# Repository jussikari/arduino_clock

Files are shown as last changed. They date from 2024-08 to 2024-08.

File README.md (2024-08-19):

# Arduino wooden clock project

## General

This is a wooden clock project which is capable of beautifully showing time, date or alternating between both. It also has the capability of setting the time and showing a welcome message when turned on.

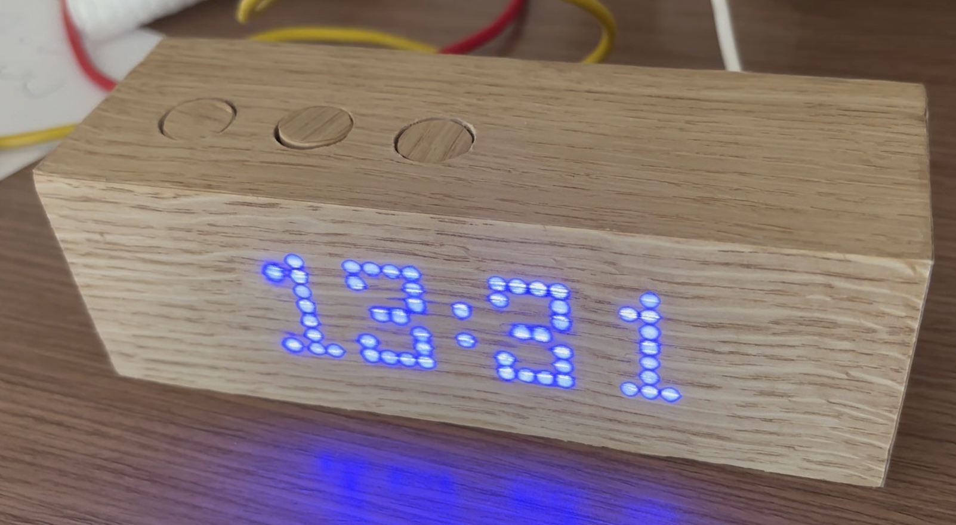
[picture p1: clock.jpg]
Clock


## Design

Construction and measurements are available in arduino_clock.scad. Open the file with OpenSCAD.

## Requirements:

- Arduino Nano (Arduino micro will also fit)
- Small perfboard for soldering
- MAX2719 4pcs 8x8 led display grids (I purchased 4 connected modules)
- RTC module (e.g. TinyRTC)
- 3pcs 10kOhm resistors
- 3pcs small push buttons
- Some wires

Also, for building the case I used 12mm veneer which I had lying around. SCAD file is for 12mm thickness. I decorated veneer with wooden film, specifically this.

https://www.aliexpress.com/item/1005005327698778.html?spm=a2g0o.order_list.order_list_main.20.3a6b1802T0AMOs

One could use something else. Or maybe spray paint the case - in which case one would need transparent film to be put on led surface for painting. Paint layer needs to be thin enough to pass through the light.

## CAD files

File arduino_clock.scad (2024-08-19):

VENEER_WIDTH = 12;
CONTAINER_HEIGHT = 32;
CONTAINER_WIDTH = 146;
BUTTON_R = 8;
BUTTON_X1 = VENEER_WIDTH + BUTTON_R + 0;
BUTTON_Y = VENEER_WIDTH + 0;
BUTTON_DIST = 20;
POWER_R = 5;
EPSILON = 0.01;

// bottom
cube([CONTAINER_WIDTH + 2 * VENEER_WIDTH, CONTAINER_HEIGHT + VENEER_WIDTH, VENEER_WIDTH]);
echo("Bottom/top: ", CONTAINER_WIDTH + 2 * VENEER_WIDTH, "x", CONTAINER_HEIGHT + VENEER_WIDTH);

// left
translate([0, 0, VENEER_WIDTH]) {
    cube([VENEER_WIDTH, CONTAINER_HEIGHT + VENEER_WIDTH, CONTAINER_HEIGHT]);
}
echo("Left/right: ", CONTAINER_HEIGHT + VENEER_WIDTH, "x", CONTAINER_HEIGHT);
    
// right    
translate([CONTAINER_WIDTH+VENEER_WIDTH, 0, VENEER_WIDTH]) {    
    cube([VENEER_WIDTH, CONTAINER_HEIGHT + VENEER_WIDTH, CONTAINER_HEIGHT]);
}

// top
translate([0, 0, CONTAINER_HEIGHT + VENEER_WIDTH]) {
    difference() {
        // top
        cube([CONTAINER_WIDTH + 2 * VENEER_WIDTH, CONTAINER_HEIGHT + VENEER_WIDTH, VENEER_WIDTH]);
        
        // button holes
        for (i = [0:2]) {
            translate([BUTTON_X1 + i * BUTTON_DIST, BUTTON_R + BUTTON_Y, -EPSILON]) {
                cylinder(h=VENEER_WIDTH + 2*EPSILON, r=BUTTON_R);
            }
        }
    }
    
    // buttons
    for (i = [0:2]) {
        translate([BUTTON_X1 + i * BUTTON_DIST, BUTTON_Y + BUTTON_R, 1]) {
            color("#ffff99") {
                cylinder(h=VENEER_WIDTH + 2*EPSILON, r=BUTTON_R - EPSILON);
            }
        }
    }
}

// backside
translate([0, CONTAINER_HEIGHT + VENEER_WIDTH, 0]) {
    difference() {
        cube([CONTAINER_WIDTH + 2 * VENEER_WIDTH, VENEER_WIDTH, CONTAINER_HEIGHT + 2 * VENEER_WIDTH]);
        translate([CONTAINER_WIDTH + VENEER_WIDTH - POWER_R, -EPSILON, VENEER_WIDTH + POWER_R]) {
            rotate([270, 0, 0]) {
                cylinder(h=VENEER_WIDTH + 2 * EPSILON, r=POWER_R);
            }
        }
        translate([VENEER_WIDTH/2, 0, VENEER_WIDTH/2]) {
            rotate([270, 0, 0]) {
                cylinder(h=VENEER_WIDTH + 2 * EPSILON, r=1);
            }
        }
        translate([CONTAINER_WIDTH+VENEER_WIDTH*1.5, 0, VENEER_WIDTH/2]) {
            rotate([270, 0, 0]) {
                cylinder(h=VENEER_WIDTH + 2 * EPSILON, r=1);
            }
        }
        translate([CONTAINER_WIDTH+VENEER_WIDTH*1.5, 0, CONTAINER_HEIGHT + VENEER_WIDTH * 1.5]) {
            rotate([270, 0, 0]) {
                cylinder(h=VENEER_WIDTH + 2 * EPSILON, r=1);
            }
        }
        translate([VENEER_WIDTH/2, 0, CONTAINER_HEIGHT + VENEER_WIDTH * 1.5]) {
            rotate([270, 0, 0]) {
                cylinder(h=VENEER_WIDTH + 2 * EPSILON, r=1);
            }
        }
    }
}
echo("Back: ", CONTAINER_WIDTH + 2 * VENEER_WIDTH, "x", CONTAINER_HEIGHT + 2 * VENEER_WIDTH);


// front film
translate([0, -EPSILON, 0]) {
    color("#000000", 0.4) {
        cube([CONTAINER_WIDTH + 2 * VENEER_WIDTH, EPSILON, CONTAINER_HEIGHT + 2 * VENEER_WIDTH]);
    }
}

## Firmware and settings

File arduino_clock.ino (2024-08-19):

#include <Arduino.h>

#include "MD_MAX72xx.h"
#include "MD_Parola.h"
#include "RTClib.h"
#include "SPI.h"

#include "font_data.h"
#include "button.h"
#include "debug.h"

// MAX7219 hardware type, size, and output pins:
#define HARDWARE_TYPE MD_MAX72XX::FC16_HW
#define MAX_DEVICES 4
#define CS_PIN 10
#define DATA_PIN 12
#define CLK_PIN 11

#define PIN_MODE 7
#define PIN_UP 6
#define PIN_DOWN 5

// Milliseconds between blinking digits in edit mode
#define BLINK_INTERVAL 200

// Milliseconds between changing time and date in alternate mode
#define ALTERNATE_INTERVAL 30000

enum State {
  STATE_INIT = 0,
  STATE_TIME = 1,
  STATE_DATE = 2,
  STATE_ALTERNATE = 3,
  STATE_EDIT
};
enum DisplayMode { TIME = 1, DATE = 2 };
enum EditMode { NONE = 0, MINUTE = 1, HOUR = 2, DAY = 3, MONTH = 4, YEAR = 5 };
struct NextView {
  bool isPending = true;
  textEffect_t effectIn = PA_SCROLL_DOWN;
  State state = STATE_TIME;
  DisplayMode displayMode = DisplayMode::TIME;
  bool showText = false;
} next;

LongPressButton modeButton(PIN_MODE);
RepeatButton upButton(PIN_UP);
RepeatButton downButton(PIN_DOWN);

int lastMinute = 0;
State state = State::STATE_INIT;
DisplayMode displayMode;

EditMode editMode = EditMode::NONE;
char displayString[10];
char hourString[3];
char minuteString[3];
char yearString[3];
char monthString[3];
char dayString[3];
unsigned long lastAlternateMillis = 0;

MD_Parola display = MD_Parola(HARDWARE_TYPE, CS_PIN, MAX_DEVICES);
RTC_DS1307 rtc;

void setString(char* str, EditMode modeMatch, int value) {
  int blink = (millis() / BLINK_INTERVAL) % 2;

  if (editMode != modeMatch || blink == 1) {
    sprintf(str, "%02d", value);
  } else {
    sprintf(str, "  ", value);
  }
}

void drawTime(textEffect_t in = PA_PRINT, textEffect_t out = PA_NO_EFFECT) {
  DateTime now = rtc.now();

  setString(hourString, EditMode::HOUR, now.hour());
  setString(minuteString, EditMode::MINUTE, now.minute());

  sprintf(displayString, "%s:%s", hourString, minuteString);
  display.setTextAlignment(PA_CENTER);
  display.setFont(0, largeDigitDont);
  display.displayText(displayString, display.getTextAlignment(),
                      display.getSpeed(), 0, in, out);
}

void drawDate(textEffect_t in = PA_PRINT, textEffect_t out = PA_NO_EFFECT) {
  DateTime now = rtc.now();

  setString(yearString, EditMode::YEAR, now.year() % 100);
  setString(monthString, EditMode::MONTH, now.month());
  setString(dayString, EditMode::DAY, now.day());

  sprintf(displayString, "%s.%s.-%s", dayString, monthString, yearString);
  display.setTextAlignment(PA_CENTER);
  display.setFont(0, smallDigitFont);
  display.displayText(displayString, display.getTextAlignment(),
                      display.getSpeed(), 0, in, out);
}

int numberOfDaysInMonth(int year, int month) {
  switch (month) {
    case 1:   // January
    case 3:   // March
    case 5:   // May
    case 7:   // July
    case 8:   // August
    case 10:  // October
    case 12:  // December
      return 31;
    case 4:   // April
    case 6:   // June
    case 9:   // September
    case 11:  // November
      return 30;
    case 2:  // February
      if ((year % 4 == 0 && year % 100 != 0) || year % 400 == 0) {
        return 29;
      } else {
        return 28;
      }
    default:
      return 0;
  }
}

void setup() {
  if (!rtc.begin()) {  // start the RTC module
    abort();
  }

  Debug::init();

  display.begin();
  display.setFont(0, nullptr);
  display.setIntensity(8); //0-15
  display.setPause(6);
  display.displayClear();

  display.displayText("Papan kello", PA_RIGHT, 130,
                      0, PA_SCROLL_LEFT, PA_SCROLL_LEFT);
}

void changeTime(int change) {
  DateTime now = rtc.now();

  if (editMode == EditMode::MINUTE) {
    rtc.adjust(DateTime(now.year(), now.month(), now.day(), now.hour(),
                        (now.minute() + change + 60) % 60, 0));

  } else if (editMode == EditMode::HOUR) {
    rtc.adjust(DateTime(now.year(), now.month(), now.day(),
                        (now.hour() + change + 24) % 24, now.minute(), 0));
  } else if (editMode == EditMode::DAY) {
    int daysInMonth = numberOfDaysInMonth(now.year(), now.month());
    rtc.adjust(
        DateTime(now.year(), now.month(),
                 (now.day() - 1 + change + daysInMonth) % daysInMonth + 1,
                 now.hour(), now.minute(), 0));
  } else if (editMode == EditMode::MONTH) {
    rtc.adjust(DateTime(now.year(), (now.month() - 1 + 12 + change) % 12 + 1,
                        now.day(), now.hour(), now.minute(), 0));
  } else if (editMode == EditMode::YEAR) {
    rtc.adjust(DateTime(2000 + (now.year() + change) % 100, now.month(),
                        now.day(), now.hour(), now.minute(), 0));
  }
}

void loop() {
  PressType modeButtonPress = modeButton.read();
  PressType upButtonPress = upButton.read();
  PressType downButtonPress = downButton.read();

  if (!next.isPending) {
    if (modeButtonPress == PRESS_TYPE_PRIMARY) {
      if (editMode == EditMode::NONE) {
        changeMode();
      } else {
        editMode = (EditMode)((editMode + 1) % 6);

        // Force redraw of current mode when exit editing
        if (editMode == EditMode::NONE) {
          lastMinute = -1;
        }
      }
    } else if (modeButtonPress == PRESS_TYPE_SECONDARY) {
      editMode = EditMode::MINUTE;
    }
  }

  DateTime now = rtc.now();

  if (editMode != EditMode::NONE && (upButtonPress == PRESS_TYPE_PRIMARY ||
                                     downButtonPress == PRESS_TYPE_PRIMARY)) {
    int change = upButtonPress == PRESS_TYPE_PRIMARY ? 1 : -1;
    changeTime(change);
  }

  if (display.displayAnimate()) {
    if (next.isPending) {
      if (next.showText) {
        char* text;
        if (next.state == STATE_TIME) {
          text = "Klo";
        } else if (next.state == STATE_DATE) {
          text = "Pvm";
        } else {
          text = "Vaihto";
        }

        display.setFont(0, nullptr);
        display.displayText(text, display.getTextAlignment(),
                            display.getSpeed(), 500, PA_OPENING_CURSOR,
                            PA_OPENING_CURSOR);

        next.showText = false;

      } else {
        display.setPause(0);
        display.setSpeed(20);
        state = next.state;
        displayMode = next.displayMode;

        if (next.displayMode == DisplayMode::TIME) {
          drawTime(next.effectIn, PA_NO_EFFECT);
        } else {
          drawDate(next.effectIn, PA_NO_EFFECT);
        }

        next.isPending = false;
      }
      return;
    }

    if (editMode != EditMode::NONE) {
      if (editMode == EditMode::HOUR || editMode == EditMode::MINUTE) {
        drawTime(PA_PRINT, PA_NO_EFFECT);
      } else {
        drawDate(PA_PRINT, PA_NO_EFFECT);
      }

      return;
    }

    if (lastMinute != now.minute()) {
      if (displayMode == TIME) {
        drawTime();
      } else {
        drawDate();
      }
    }

    if (state == STATE_ALTERNATE) {
      if (millis() - lastAlternateMillis > ALTERNATE_INTERVAL) {
        lastAlternateMillis = millis();
        textEffect_t effect =
            displayMode == TIME ? PA_SCROLL_UP : PA_SCROLL_DOWN;
        if (displayMode == TIME) {
          drawTime(PA_PRINT, effect);
        } else {
          drawDate(PA_PRINT, effect);
        }
        next.effectIn = effect;
        next.isPending = true;
        next.showText = false;
        next.displayMode =
            displayMode == TIME ? DisplayMode::DATE : DisplayMode::TIME;
      }
    }

    lastMinute = now.minute();
  }
}

void changeMode() {
  if (displayMode == DisplayMode::TIME) {
    drawTime(PA_PRINT, PA_OPENING_CURSOR);
  } else {
    drawDate(PA_PRINT, PA_OPENING_CURSOR);
  }

  if (state == STATE_TIME) {
    next.state = STATE_DATE;
  } else if (state == STATE_DATE) {
    next.state = STATE_ALTERNATE;
  } else {
    next.state = STATE_TIME;
  }

  next.displayMode =
      next.state == STATE_DATE ? DisplayMode::DATE : DisplayMode::TIME;
  next.effectIn = PA_OPENING_CURSOR;
  next.isPending = true;
  next.showText = true;
  lastAlternateMillis = millis();
}

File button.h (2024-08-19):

#ifndef button_h
#define button_h
#include <Arduino.h>

const int DEBOUNCE_DELAY = 30;
const int REPEAT_DELAY = 200;
const int LONG_PRESS_DELAY = 1000;

enum PressType {
  PRESS_TYPE_NONE = 0,
  PRESS_TYPE_PRIMARY = 1,
  PRESS_TYPE_SECONDARY = 2
};

enum PressStatus {
  PRESS_STATUS_NONE = 0,
  PRESS_STATUS_ACTIVATED = 1,
  PRESS_STATUS_LONG = 2
};

class Button {
 public:
  Button(int pin);
  virtual PressType read();

 protected:
  int _pin;
  int _lastButtonState = LOW;
  unsigned long _lastDebounceTime = 0;
  PressStatus _pressStatus = PRESS_STATUS_NONE;
};

class LongPressButton : Button {
 public:
  LongPressButton(int pin) : Button(pin){};
  PressType read() override;
};

class RepeatButton : Button {
 public:
  RepeatButton(int pin) : Button(pin){};
  PressType read() override;
};

#endif
